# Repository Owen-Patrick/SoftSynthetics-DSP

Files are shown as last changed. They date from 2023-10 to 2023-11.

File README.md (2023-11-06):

# Soft Synthetics DSP Adapator
This Repository Contains hardware for adapting a cheap Karaoke DSP board to eurorack.

It turns one of these:
s-l1600

into an 10HP eurorack stereo multi-effects module with some fun clock modulation voltage control:
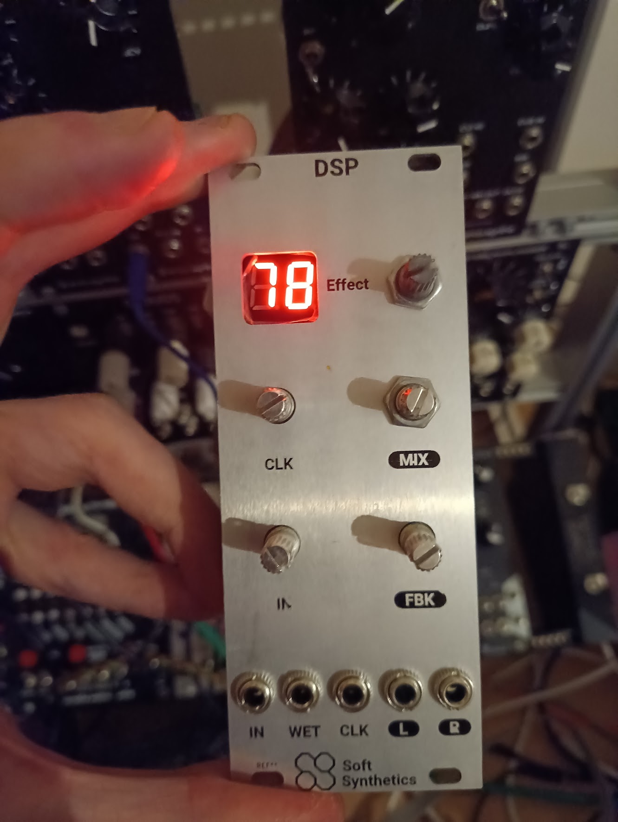
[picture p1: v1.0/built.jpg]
DSP built


## What's provided
This repository contains:
* Kicad Circuit layout
* Kicad PCB and panel layouts
* Gerbers for the panel and circuit boards

## Learn More
More information is avaialbe here: 
Soft Synthetics Website

## Caveats
v1.1 This is an untested revision of the original board which had some clearance issues. I believe they have been rectified but please do double check! I have not printed it because v1.0 did work with plenty of bodging which I do not recommend.

THe clock modulator circuit requires a fairly simple modifaction to the board in order to override the clock input (x). All you have to do is remove the crystal and replace with in a header to connect "x" instead, which is a new clock siglan being generated by the pt2399. From what I can tell, the frequency of the DSP boards clock changes between manufacturers so experimentation to find the ideal frequency and modulation amount. If that doesn't excite then you could just modify the PCB layout and remove that whole part of the circuit from the PCB and front panel. 

It's also not the prettiest in constuction and requires some pretty cosy bends of the cables that connect the DSP boards display and main board (i've seen some folk replace that cable with softer wires). The final consution is as so:

*the display board attaches to the main back board of via 2 M3 stadnoffs.
*That display board connects to the interface with an m3 standoff and 2.54mm pin headers. 
*The DSP processor board mounts to the interface.
*The cables fit together that way you'd expect: x to the clock in, in, Lout, Rout to the DSP PCB, and 5v to power in of the DSP. 

If I have time i'll make a little diagram at some point! until then it mostly makes sense.

## Mentions 
This project is a culmination of various other creators work into one package which shares the benefits they each brung to the table. Those insanley talented peaople are:

*Modular for the Masses (Junito Moore) - "My Favourite Reverb"
        I adopted the wonderfully creative clock control using a PT2399 chip.
*Jos from LMNC forums - Reverb-o-matic
*I took inspiration from single gang pot Wet/Dry mixer used in this scehmatic
    Hagiwo - 2500円で作るDSPマルチエフェクター-モジュラーシンセ自作
    Hagiwo is a powerhouse in making lovely, innovative, and accessable DIY modules. They put me onto this device in the first place

## License 
CC BY-SA 4.0
which . AKA be nice :)

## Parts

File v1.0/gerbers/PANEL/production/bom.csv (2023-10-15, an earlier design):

Designator | Footprint | Quantity | Value | LCSC Part #
_3, _2, |  | 3

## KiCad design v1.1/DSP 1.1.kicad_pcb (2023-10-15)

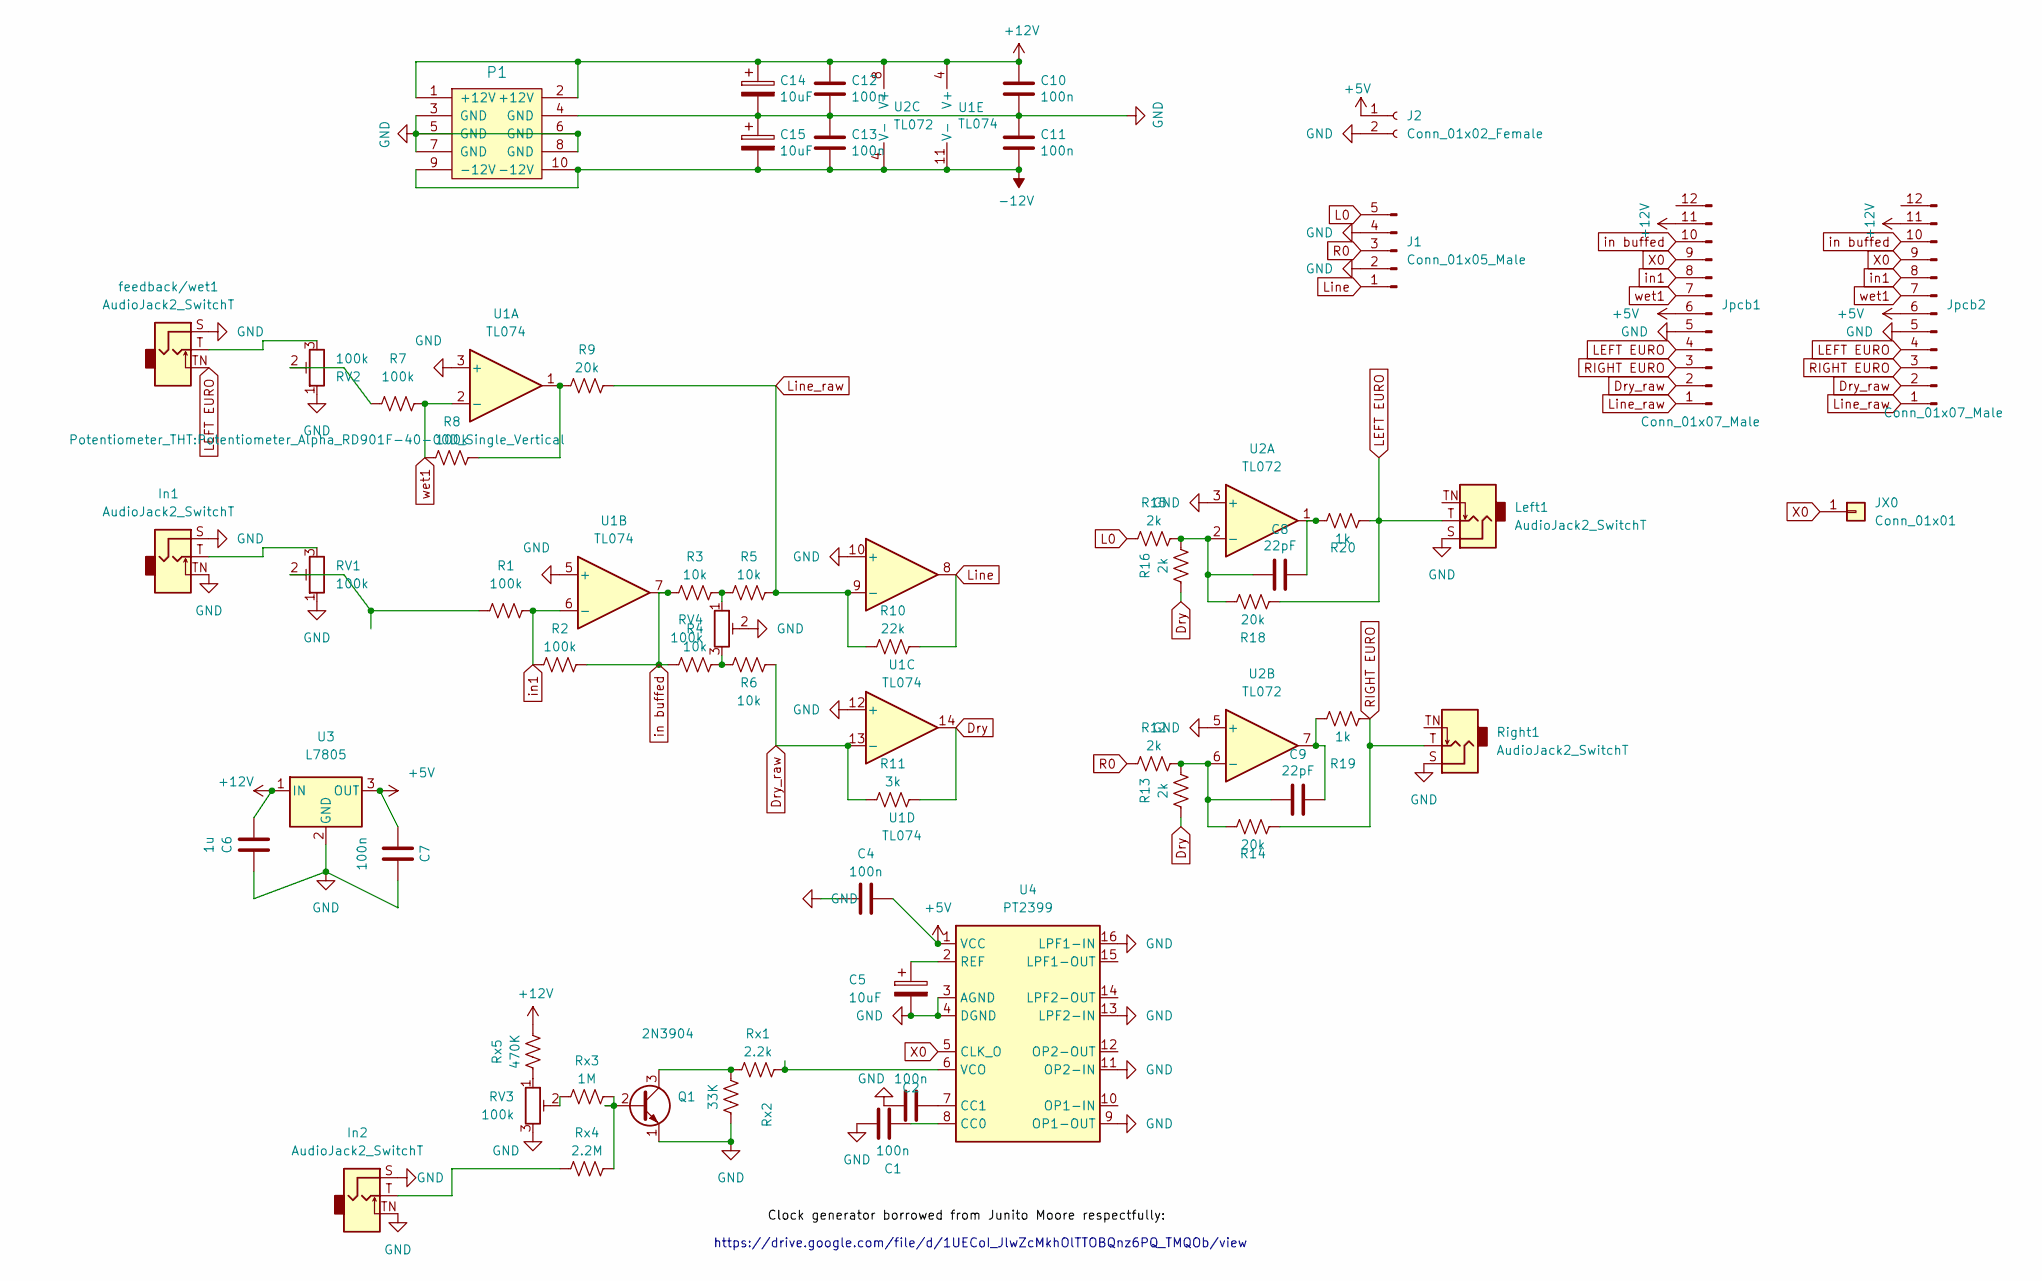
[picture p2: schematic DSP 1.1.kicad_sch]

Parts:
C1, C2, C4, C7: 100n; C_Axial_L5.1mm_D3.1mm_P10.00mm_Horizontal
C5: 10uF; CP_Radial_D6.3mm_P2.50mm
C6: 1u; C_Axial_L5.1mm_D3.1mm_P10.00mm_Horizontal
C8, C9: 22pF; C_Disc_D7.5mm_W2.5mm_P5.00mm
C10, C11: 100n; C_Disc_D7.5mm_W2.5mm_P5.00mm
C12, C13: 100n; C_0805_2012Metric_Pad1.15x1.40mm_HandSolder
C14, C15: 10uF; CP_Radial_D5.0mm_P2.50mm
In1, In2: AudioJack2_SwitchT; Jack_3.5mm_QingPu_WQP-PJ398SM_Vertical_CircularHoles
J1: Conn_01x05_Male; PinHeader_1x05_P2.54mm_Vertical
J2: Conn_01x02_Female; PinHeader_1x02_P2.54mm_Vertical
JX0: Conn_01x01; PinHeader_1x01_P2.54mm_Vertical
Jpcb1, Jpcb2: Conn_01x07_Male; PinHeader_2x06_P2.54mm_Vertical
Left1: AudioJack2_SwitchT; Jack_3.5mm_QingPu_WQP-PJ398SM_Vertical_CircularHoles
P1: EURO_PWR_2x5; IDC-2x5
Q1: 2N3904; TO-92_Inline
R1, R2, R7, R8: 100k; R_Axial_DIN0207_L6.3mm_D2.5mm_P10.16mm_Horizontal
R3, R4, R5, R6: 10k; R_Axial_DIN0207_L6.3mm_D2.5mm_P10.16mm_Horizontal
R9, R14, R18: 20k; R_Axial_DIN0207_L6.3mm_D2.5mm_P10.16mm_Horizontal
R10: 22k; R_Axial_DIN0207_L6.3mm_D2.5mm_P10.16mm_Horizontal
R11: 3k; R_Axial_DIN0207_L6.3mm_D2.5mm_P10.16mm_Horizontal
R12, R13, R15, R16: 2k; R_Axial_DIN0207_L6.3mm_D2.5mm_P10.16mm_Horizontal
R19, R20: 1k; R_Axial_DIN0207_L6.3mm_D2.5mm_P10.16mm_Horizontal
RV1, RV2, RV3, RV4: 100k; Potentiometer_Alpha_RD901F-40-00D_Single_Vertical
Right1: AudioJack2_SwitchT; Jack_3.5mm_QingPu_WQP-PJ398SM_Vertical_CircularHoles
Rx1: 2.2k; R_Axial_DIN0207_L6.3mm_D2.5mm_P10.16mm_Horizontal
Rx2: 33K; R_Axial_DIN0207_L6.3mm_D2.5mm_P10.16mm_Horizontal
Rx3: 1M; R_Axial_DIN0207_L6.3mm_D2.5mm_P10.16mm_Horizontal
Rx4: 2.2M; R_Axial_DIN0207_L6.3mm_D2.5mm_P10.16mm_Horizontal
Rx5: 470K; R_Axial_DIN0207_L6.3mm_D2.5mm_P10.16mm_Horizontal
U1: TL074; DIP-14_W7.62mm_LongPads
U2: TL072; DIP-8_W7.62mm_LongPads
U3: L7805; TO-220-3_Horizontal_TabDown
U4: PT2399; DIP-16_W7.62mm_LongPads
feedback/wet1: AudioJack2_SwitchT; Jack_3.5mm_QingPu_WQP-PJ398SM_Vertical_CircularHoles

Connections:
+5V: C4.2, C7.2, J2.1, Jpcb1.6, Jpcb2.6, U3.3 (OUT), U4.1 (VCC)
+12V: C6.2, C10.2, C12.2, C14.1, Jpcb1.11, Jpcb2.11, P1.1 (+12V), P1.2 (+12V), Rx5.2, U1.4 (V+), U2.8 (V+), U3.1 (IN)
-12V: C11.1, C13.1, C15.2, P1.9 (-12V), P1.10 (-12V), U1.11 (V-), U2.4 (V-)
Dry: R11.2, R13.1, R16.1, U1.14
Dry_raw: Jpcb1.2, Jpcb2.2, R6.2, R11.1, U1.13 (-)
GND: C1.1, C2.1, C4.1, C5.2, C6.1, C7.1, C10.1, C11.2, C12.1, C13.2, C14.2, C15.1, In1.S, In1.TN, In2.S, In2.TN, J1.2, J1.4, J2.2, Jpcb1.5, Jpcb2.5, Left1.S, P1.3 (GND), P1.4 (GND), P1.5 (GND), P1.6 (GND), P1.7 (GND), P1.8 (GND), Q1.1 (E), RV1.1, RV2.1, RV3.3, RV4.2, Right1.S, Rx2.1, U1.3 (+), U1.5 (+), U1.10 (+), U1.12 (+), U2.3 (+), U2.5 (+), U3.2 (GND), U4.3 (AGND), U4.4 (DGND), U4.9 (OP1-OUT), U4.11 (OP2-IN), U4.13 (LPF2-IN), U4.16 (LPF1-IN), feedback/wet1.S
L0: J1.5, R15.1
LEFT EURO: Jpcb1.4, Jpcb2.4, Left1.T, R18.1, R20.1, feedback/wet1.TN
Line: J1.1, R10.2, U1.8
Line_raw: Jpcb1.1, Jpcb2.1, R5.2, R9.2, R10.1, U1.9 (-)
unnamed: C1.2, U4.8 (CC0)
unnamed: C2.2, U4.7 (CC1)
unnamed: C5.1, U4.2 (REF)
unnamed: C8.1, R15.2, R16.2, R18.2, U2.2 (-)
unnamed: C8.2, R20.2, U2.1
unnamed: C9.1, R12.2, R13.2, R14.2, U2.6 (-)
unnamed: C9.2, R19.2, U2.7
unnamed: In1.T, RV1.3
unnamed: In2.T, Rx4.1
unnamed: Q1.2 (B), Rx3.2, Rx4.2
unnamed: Q1.3 (C), Rx1.1, Rx2.2
unnamed: R1.1, RV1.2
unnamed: R3.2, R5.1, RV4.1
unnamed: R4.2, R6.1, RV4.3
unnamed: R7.1, RV2.2
unnamed: R8.2, R9.1, U1.1
unnamed: RV2.3, feedback/wet1.T
unnamed: RV3.1, Rx5.1
unnamed: Rx1.2, U4.6 (VCO)
R0: J1.3, R12.1
RIGHT EURO: Jpcb1.3, Jpcb2.3, R14.1, R19.1, Right1.T
X0: JX0.1, Jpcb1.9, Jpcb2.9, U4.5 (CLK_O)
in1: Jpcb1.8, Jpcb2.8, R1.2, R2.1, U1.6 (-)
in buffed: Jpcb1.10, Jpcb2.10, R2.2, R3.1, R4.1, U1.7
wet1: Jpcb1.7, Jpcb2.7, R7.2, R8.1, U1.2 (-)

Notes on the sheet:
https://drive.google.com/file/d/1UECoI_JlwZcMkhOlTTOBQnz6PQ_TMQOb/view

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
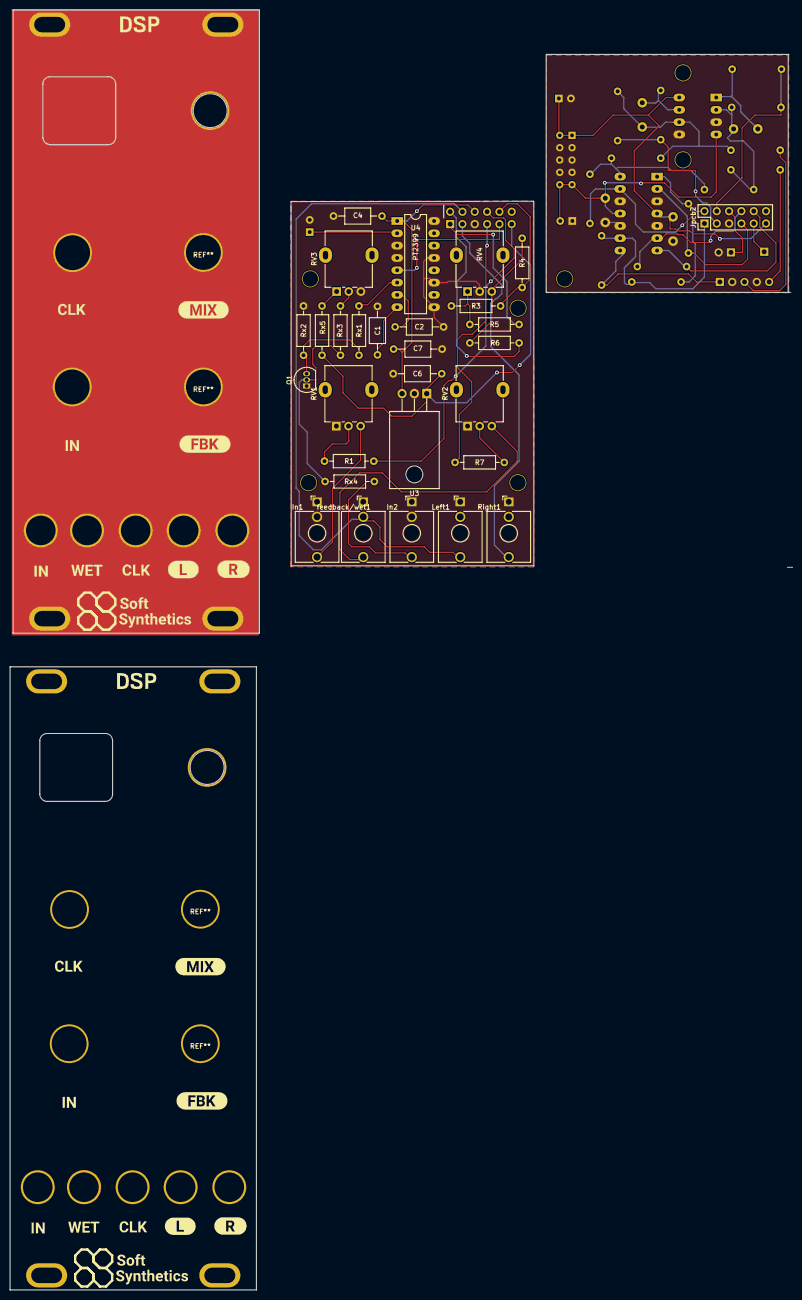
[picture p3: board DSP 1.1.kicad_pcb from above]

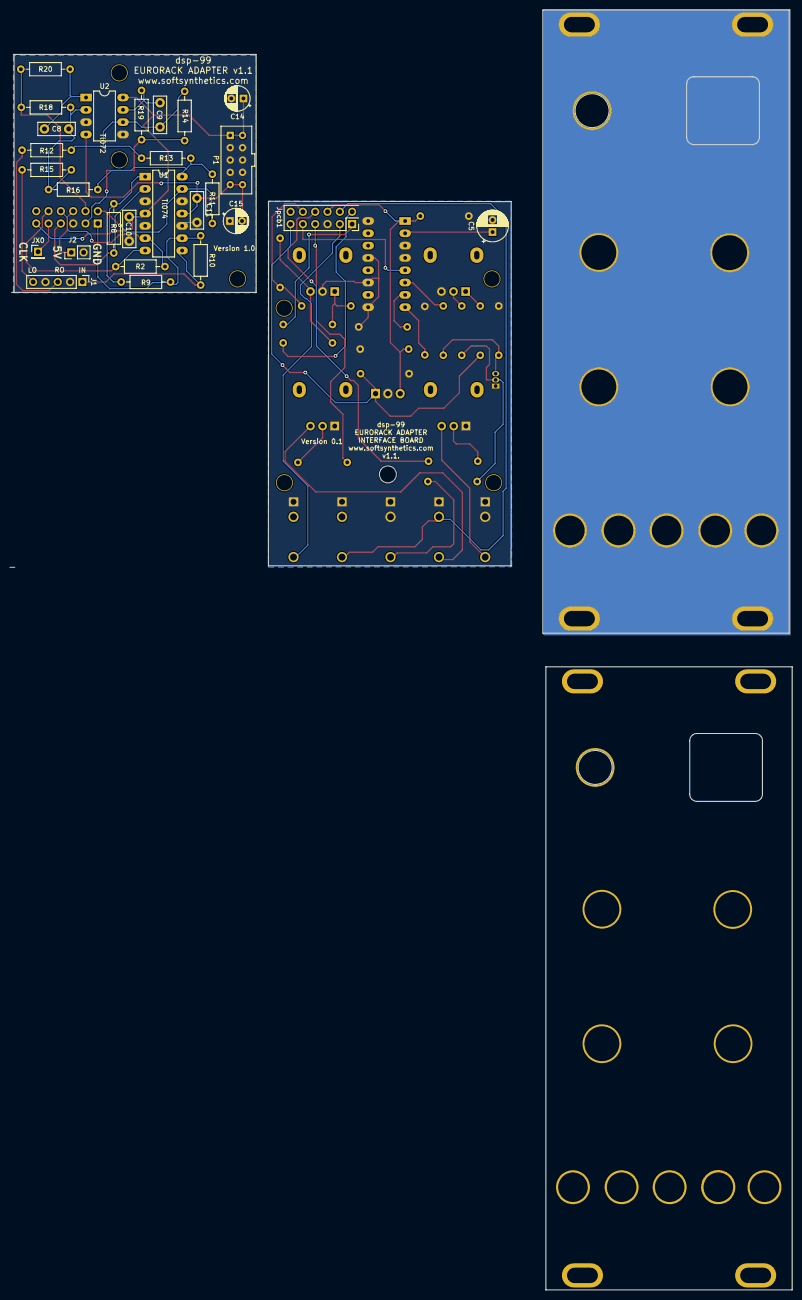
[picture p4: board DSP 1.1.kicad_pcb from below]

Board: 2 copper layers, 161.3 x 263.9 mm, 80 parts (26 on the bottom side), 35 nets.

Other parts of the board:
kibuzzard-64D80CCD, kibuzzard-64D80CCD#2: G***; kibuzzard-64D80CCD
kibuzzard-643BAF55, kibuzzard-643BAF55#2, kibuzzard-643BAF55#3, kibuzzard-643BAF55#4: G***; kibuzzard-643BAF55
kibuzzard-643BAFC1, kibuzzard-643BAFC1#2: G***; kibuzzard-643BAFC1
kibuzzard-643BAFCE, kibuzzard-643BAFCE#2, kibuzzard-643BAFCE#3, kibuzzard-643BAFCE#4: G***; kibuzzard-643BAFCE
kibuzzard-643BB3B1, kibuzzard-643BB3B1#2: G***; kibuzzard-643BB3B1
kibuzzard-643BB32E, kibuzzard-643BB32E#2: G***; kibuzzard-643BB32E
kibuzzard-643BB339, kibuzzard-643BB339#2: G***; kibuzzard-643BB339
kibuzzard-643BB390, kibuzzard-643BB390#2: G***; kibuzzard-643BB390
kibuzzard-644033EB, kibuzzard-644033EB#2: G***; kibuzzard-644033EB
kibuzzard-644033FD, kibuzzard-644033FD#2: G***; kibuzzard-644033FD
